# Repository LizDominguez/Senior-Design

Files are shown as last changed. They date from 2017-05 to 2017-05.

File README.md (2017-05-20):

# Senior-Design
An IoT project including an RFID reader that updates a website listing adoptable pets. 

MYshelter is an animal shelter management system that keeps track of the pets that are surrendered and adopted. 
Each animal is given an RF tag with a unique ID. 
The ID is scanned once when the animal is surrendered to the shelter, and a second time once the animal is adopted. 
This information will be sent to a database that keeps track of the animals and other relevant information.

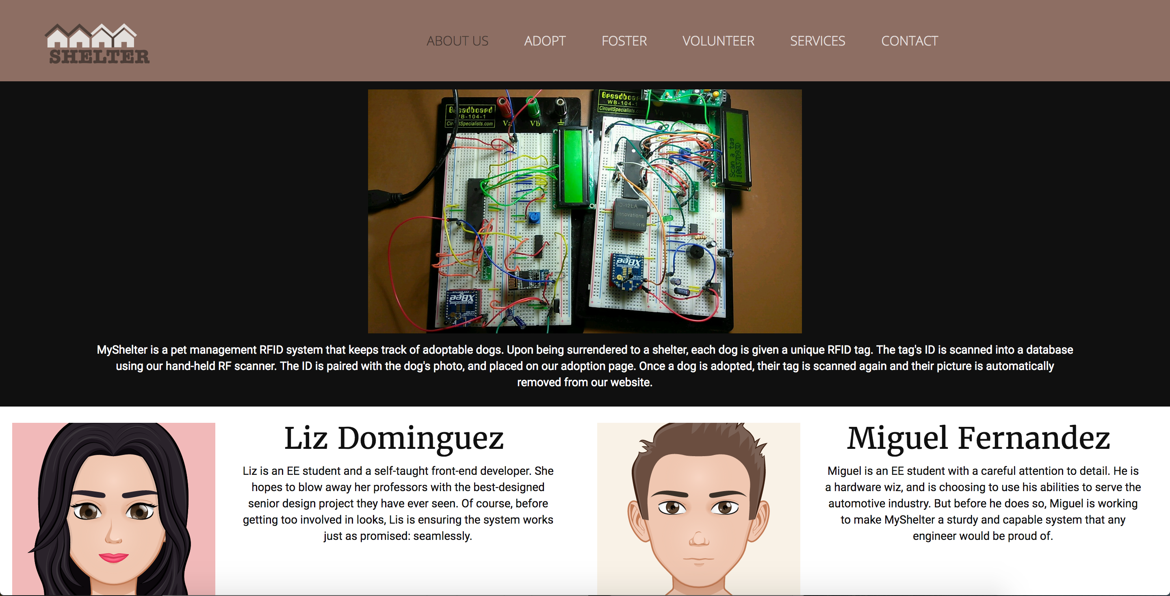
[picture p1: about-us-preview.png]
 
The MyShelter Website

Project Features:

This design requires RFID tags, a receiver circuit, and a Wi-Fi module. 
The receiver will use a 125kHz carrier signal to power the RFID tag via an antenna. 
An AM signal demodulator will retrieve the stored information on the RFID tag in digital form. 
Amplifiers will be used in the receiver circuit to amplify the analog signals for better data interpretation. 
The microprocessor will then retrieve the signal information and decode it. The microprocessors uses UARTs, LCDs, XBEEs, the PWM, timers,
interrupts, ISP, a wifi module, and other features.

<div align="center">

Watch the video (https://youtu.be/Qfhe00SMSjw)

Click to watch the project in action
</div>

For more information, view the <a href="https://github.com/LizDominguez/Senior-Design/blob/master/Final%20Report.pdf">design report</a>.

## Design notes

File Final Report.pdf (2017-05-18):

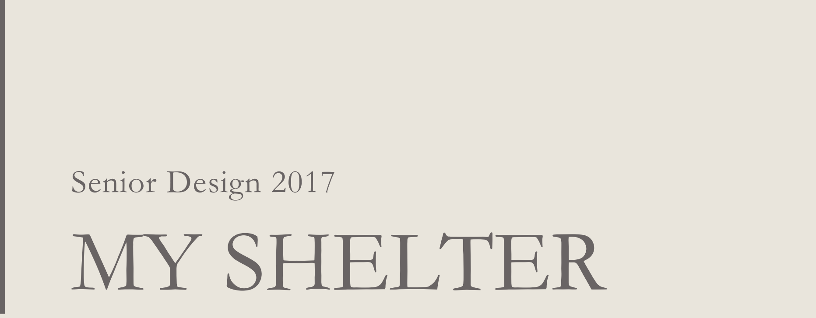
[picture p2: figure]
Senior Design 2017 MY SHELTER
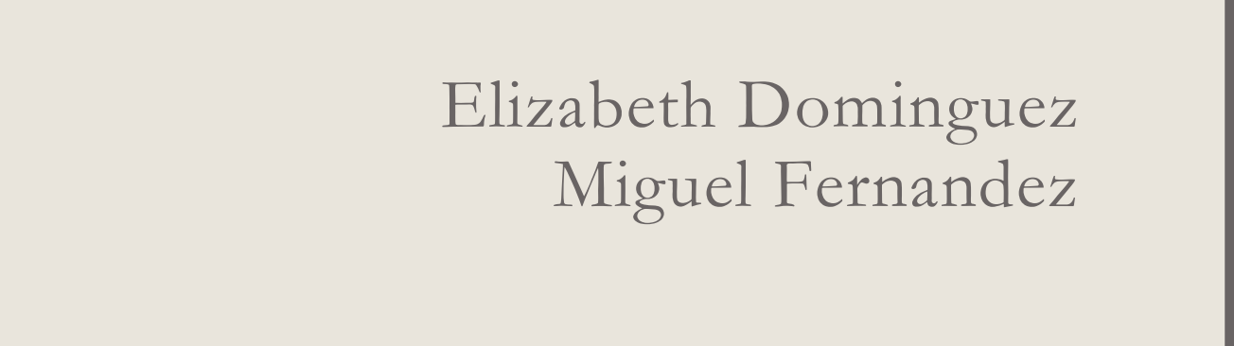
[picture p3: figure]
Elizabeth Dominguez Miguel Fernandez

## Project Abstract

MYshelter is an animal shelter management system that keeps track of the pets that are surrendered and adopted. Each animal is given an RF tag with a unique ID, like the one shown in Figure 1. The ID is scanned once when the animal is surrendered to the shelter, and a second time once the animal is adopted. This information will be sent to a database that keeps track of the animals and other relevant information. An example of what may appear on the database is shown in Table 1.

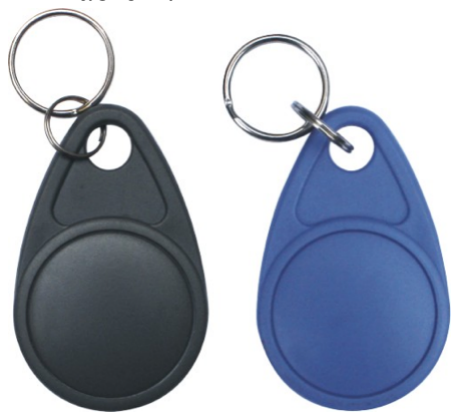
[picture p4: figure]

FIGURE 1 RF TAG GIVEN TO EACH PET

TABLE 1 INFORMATION STORED IN DATABASE

ID | TYPE | BREED | STATUS
12345 | DOG | HUSKY | SURRENDERED
23456 | CAT | TABBY | ADOPTED

The information on this database will then be used on an adoption website Figure 2. The website will showcase pictures of the available pets. If an animal is adopted, its picture will be blurred out on the website once the page is refreshed. The website also has an administration page that allows users to change the IDs of each dog without having to scan the tag.

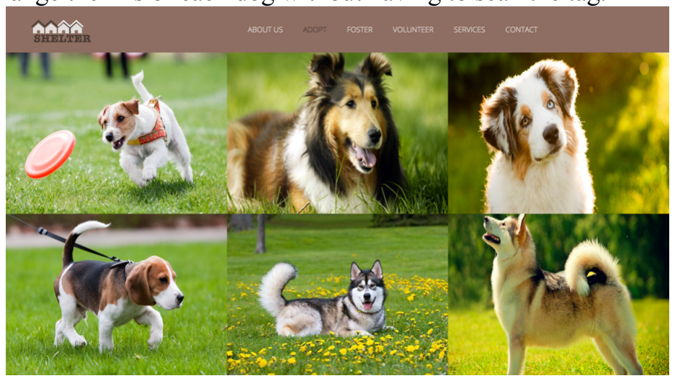
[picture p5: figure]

FIGURE 2 THE MYSHELTER WEBSITE

Project Features
This design requires RFID tags, a receiver circuit, and a Wi-Fi module. The receiver will use a 125kHz carrier signal to power the RFID tag via an antenna. An AM signal demodulator will retrieve the stored information on the RFID tag in digital form. The receiver must obtain information accurately with minimal interference. Amplifiers will be used in the receiver circuit to amplify the analog signals for better data interpretation. The microprocessor will then retrieve the signal information and decode it.

Our design will be split into two systems: the mainboard with the Wi-Fi module, and a handheld RF module. Both systems use an LCD and XBEEs to communicated via UART. The receiver module is also hooked up to an AB amplifier and an 8 ohm speaker that beeps whenever a card is successfully read. Our system is powered by two 6V wall plugs and on/off switches.
Concept & Technology Selection
Our design will include the following components:
- 2 Atmega644PA
- RF Antenna
- RFID cards
- Receiver
- 2 LCDs
- 2 XBEEs
- Wi-Fi module
- AB amplifier and 8 ohm speaker
- Power Connectors

## RF Reader

Our RF reader reads 125 kHz tags and uses the EM4100 protocol to produce level transitions in the middle of a bit period. A low to high transition signifies a logic of 1, and a high to low transition signifies a 0. When the tag approaches the electromagnetic field of the antenna, it sends out a stream of bits shown in Figure 3. The first 9 bits are 1s, used to indicate the beginning of a read. They are followed by 8 customer ID numbers, each with their own parity bits. Then 32 data bits and their parities are sent as the card ID. Finally, 4 column parity bits and 1 stop bit are transmitted for a total of 64 bits.

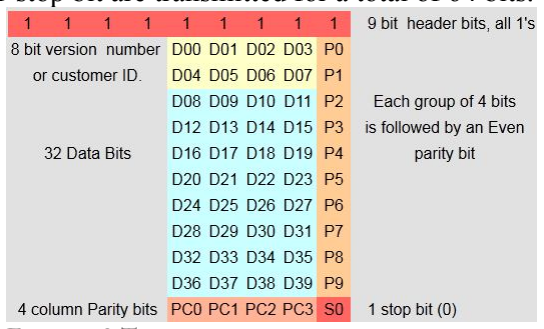
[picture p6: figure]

FIGURE 3 THE TRANSMITTED BIT STREAM

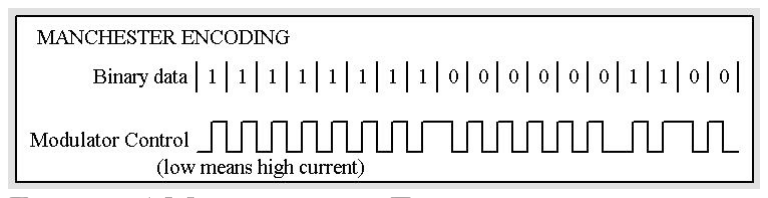
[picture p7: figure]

FIGURE 4 MANCHESTER ENCODING

In order to combat the noise in our receiver circuit, we attached bypass capacitors to power lines in addition to a Schmitt trigger. A Schmitt trigger is a comparator with hysteresis that converts analog to digital. Its output changes only when the input changes past a second threshold.
A 125kHz square wave is generated via counter 2 on PIND7 and fed into the input of the receiver. The output of the receiver is then connected to an input pin of the microcontroller. Using a 16-bit, timer, we store the logic value ever 500 us into a large buffer. Then a counter counts each set of 9 1s—whenever the input pin reads 0, it resets the count to 0 to only account for consecutive 1s. Another array then stores where each consecutive 9 1s are in the buffer and increments this value to begin at the first value of the 50 card ID values and parity bits.
Once the buffer is full, the data is decoded. Each bit is shifted 4 times to create a 4-bit integer. The parity and column parity bits are saved. We then calculate what the column and row parity bits should be in a separate loop. If the scanned and calculated parity bits do not match, we do not print the value. Only when we have a perfect read to we print he values we scanned.

## AB Amplifier

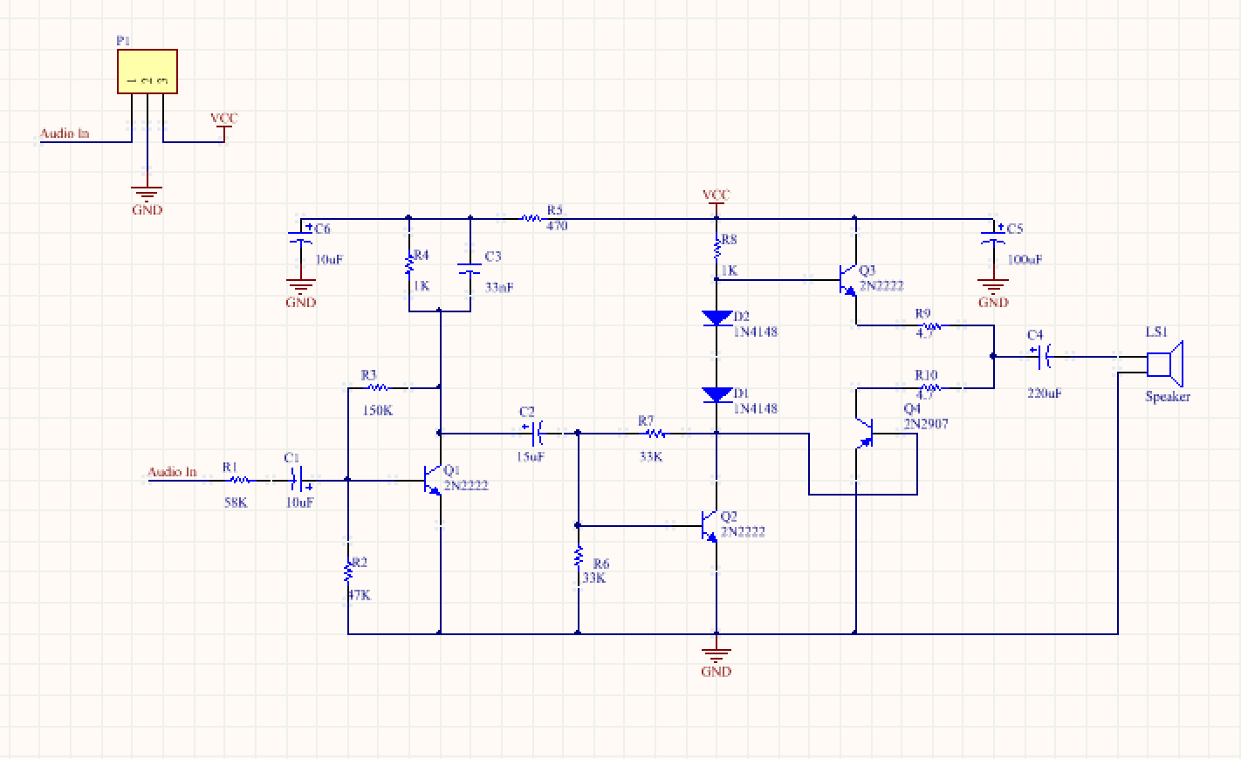
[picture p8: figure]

FIGURE 5 AB AMPLIFIER CIRCUIT

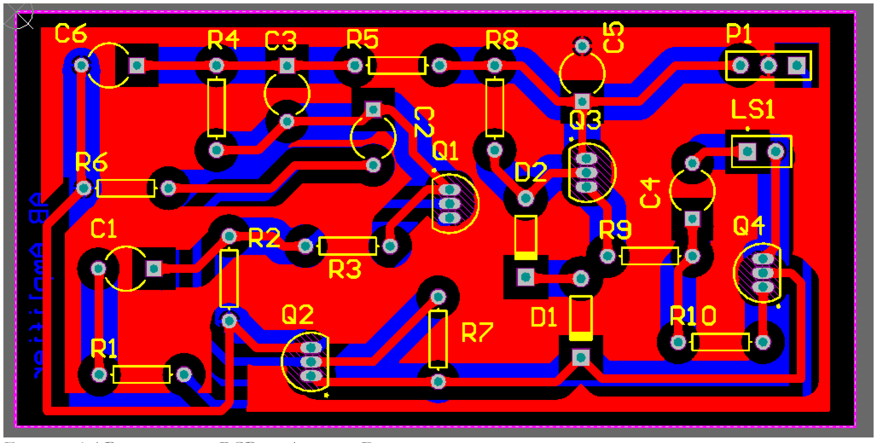
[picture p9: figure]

FIGURE 6 AB AMPLIFIER PCB IN ALTIUM DESIGNER
Preamplifier Stage
Transistor Q1 and the surrounding components act as a preamplifier. A preamplifier is a component that provides a small gain to a signal before it is fed to an amplifier with a greater gain. This is done because many audio sources have a small output voltage that would not be enough to drive a speaker. The preamplifier stage also acts as a volume control and noise filter. Transistor Q1 is dual feedback biased using R2, R3, and R4. Biasing sets the transistor DC operating voltage and current to the levels that prevents the AC signal from clipping. It is done because transistors cannot conduct if the voltage/current is negative, which it is in an audio signal. Therefore, the input signal must be shifted into the positive region.
This can be done with collector feedback biasing, also called self-biasing, using R3 and R4. Referring to figure 3, self-biasing works in the following way: If Ic increases, Vc decreases, reducing the base drive and automatically reducing collector current (keeping the Q point fixed). Negative feedback is supplied via Rb1 so that when the load current increases, Vc decreases, causing Ib to decrease, and bringing Ic back to normal. Adding R2 to the circuit makes it dual feedback biased, providing additional stability through automatic biasing and Rf feedback.

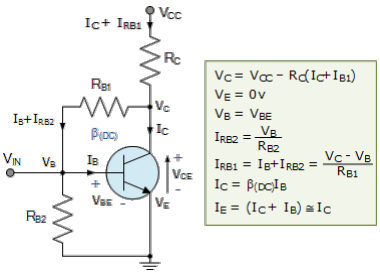
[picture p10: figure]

FIGURE 7 DUAL FEEDBACK BIASING

Driver Stage
Q2 acts as the driver stage. The driver stage’s purpose is to produce enough current gain to drive the output stage. This in turn causes a gain in power.
AB push pull
Transistors Q3 and Q4 and diodes D1 and D2 form part of the push-pull stage with diode biasing. Temperature can vary the base-emitter voltage. This can be prevented by forward biasing via two diodes. The alternating transistors source or sink the load current, which improves efficiency, increases the power output, cancels even harmonics, and cancels DC current at the output.

## Wi-Fi Module

For our Wi-Fi module, we chose the ESP8266, shown below. This module is used most often by hobbyists and beginners due to its short and simple AT commands. It is also one of the cheapest modules on the market, at only $3.00. Just a few years ago, Wi-Fi modules were priced at over $50!

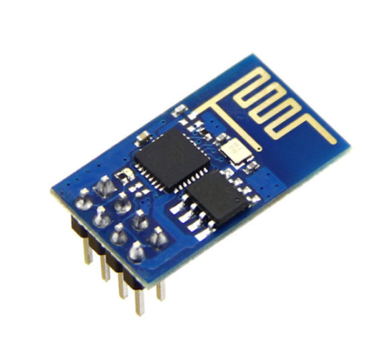
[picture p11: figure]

FIGURE 8 THE ESP8266 MODULE

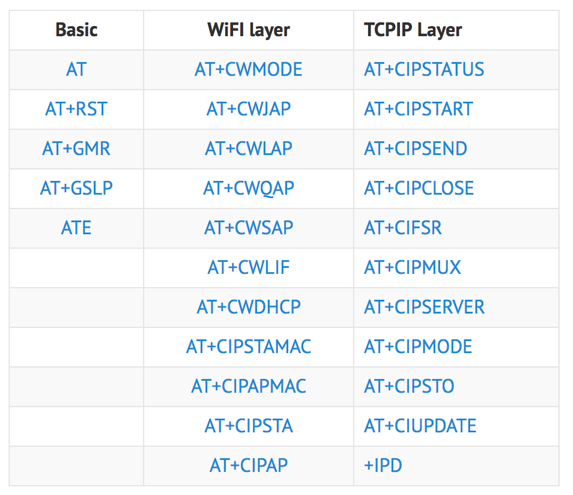
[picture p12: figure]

FIGURE 1 ALL KNOWN AT COMMANDS

We utilized a mobile hotspot to share access to our phone’s wireless network connection with the Wi-Fi module. Wi-Fi utilizes radio waves at a frequency of 2.4 or 5 GHz to establish a connection to a network. Once data is translated into a radio signal, an antenna will transmit to a router. The data is then decoded and sent through the internet via an Ethernet cable. The speed and frequency of transmission are highlighted by the 802.11 network standards a, b, g, and n. Once a connection is established, we send an HTTP request to our server hosted on Amazon Web Services (AWS). HTTP is short for hypertext transfer protocol. When an HTTP request is submitted to a server, the server returns a response message.
A server is a resource provider. It holds HTML files and other content. It can be accessed via a web browser, remote client, or ssh remote login. The server itself is made up of a local client, or a program on the same machine as the server, like MySQL. To pass SQL queries to the server, a programmer must use a scripting language. Initially we considered using JavaScript as our primary scripting language, used solely for web browsers. However, we opted for a simpler general-purpose language called Python.
Connecting to a server also requires an IP address. An Internet Protocol address consists of four numbers ranging from 0 to 255 that designate the destination of the information we send. We also include a port number at which the virtual machine listens in for data.
The Wi-Fi module communicates with the Atmega644PA via UART at 9600 baud. UART0 listens in for the RF ID being sent from the XBEE. The ID is compared to a structure array holding all card values. When there’s a match, the microcontroller then decides the status of the dog and prints it on the LCD along with the card ID. Initially, a dog is surrendered and already on the website. Once the card is scanned again, and the dog’s status changes, the Wi-FI module sends a GET request—to the server with the card ID and the status in order to override the current status stored in an SQL table. Then python executes the script responsible for changing the dog’s picture on the front-end of the website. When a person visits the website, the browser will send a GET request to the server to generate the HTML files.

## Final Design Schematics and PCBs

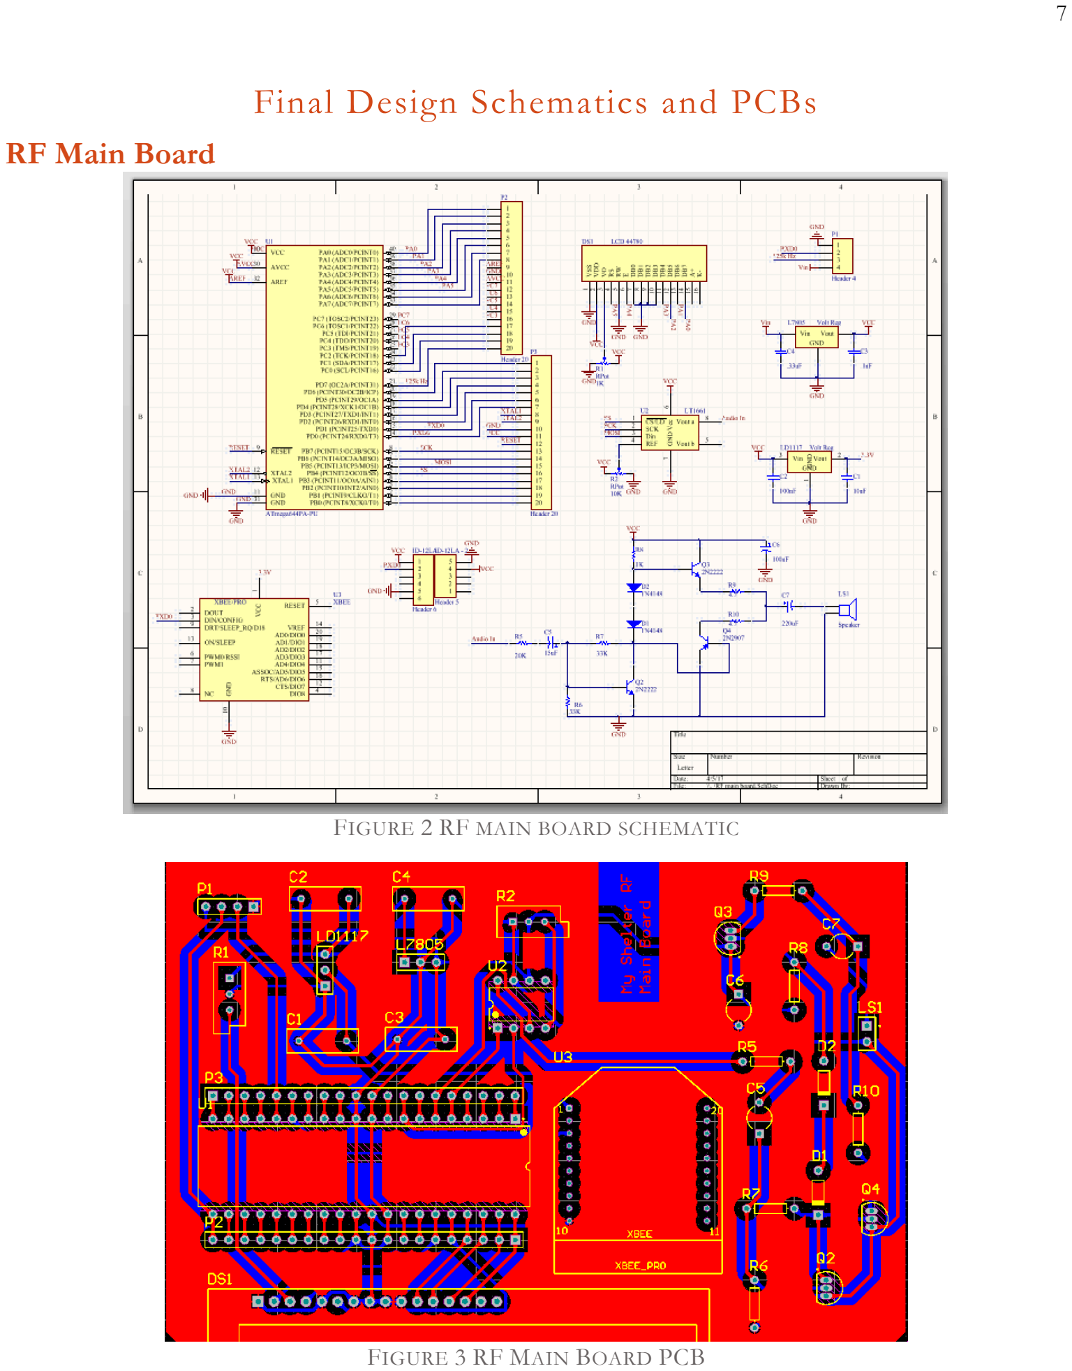
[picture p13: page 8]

RF Main Board

FIGURE 2 RF MAIN BOARD SCHEMATIC

FIGURE 3 RF MAIN BOARD PCB

Wi-FI Main Board

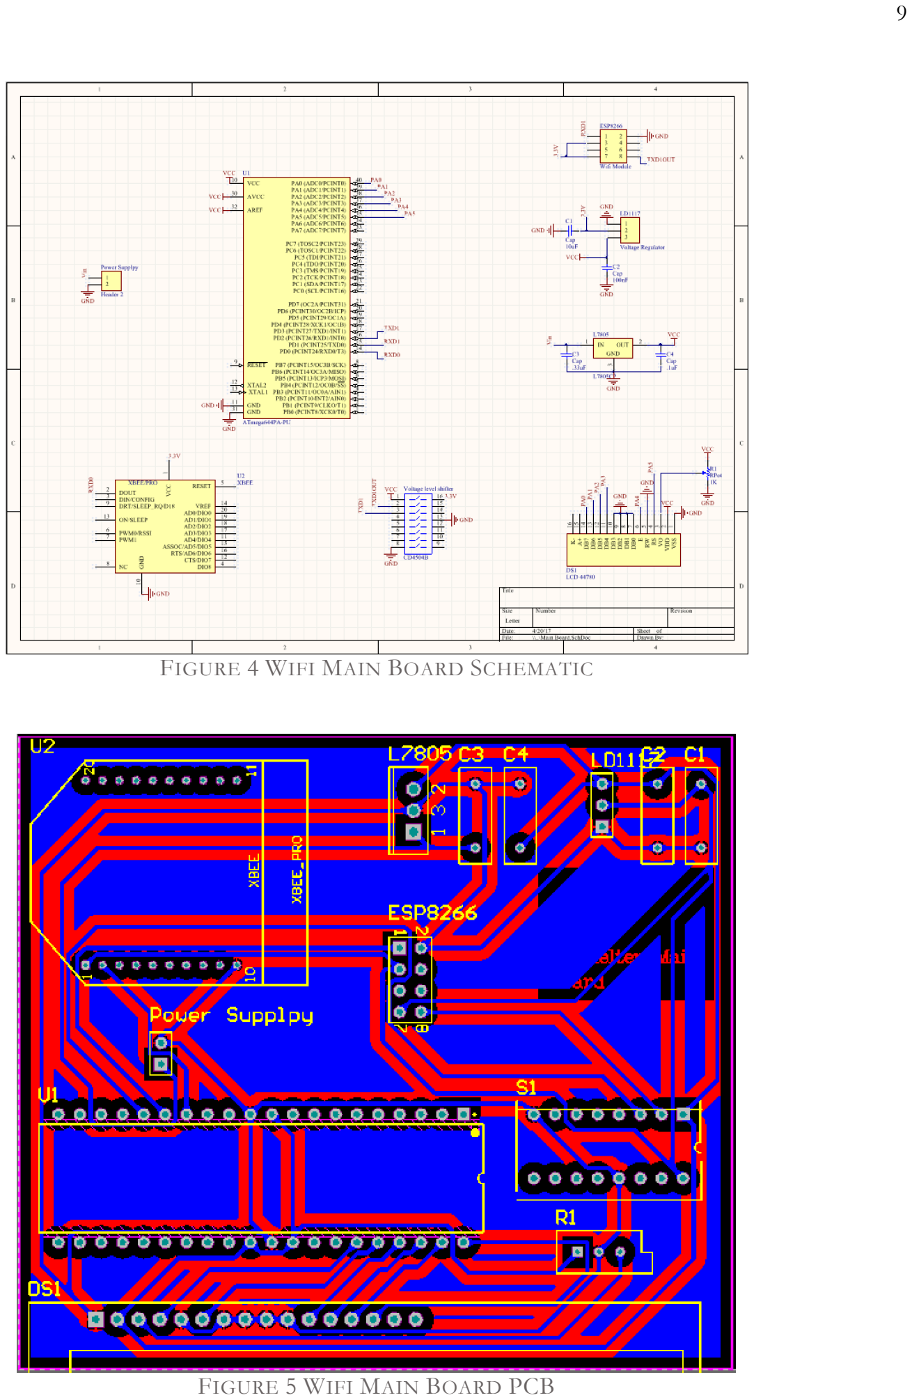
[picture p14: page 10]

FIGURE 4 WIFI MAIN BOARD SCHEMATIC

FIGURE 5 WIFI MAIN BOARD PCB

## Work Break-Down

Task | Liz | Miguel
RFID Receiver | 0% | 100%
Battery Charging Circuit | 0% | 100%
AB Amplifier | 100% | 0%
Main Board Programming | 100% | 0%
Main Board PCB | 0% | 100%
Database & Website | 100% | 0%
RF Programming | 90% | 10%
RF PCB | 70% | 30%
Case | 0% | 100%

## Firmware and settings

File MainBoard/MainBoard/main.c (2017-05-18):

#define F_CPU 8000000UL
#include <avr/io.h>
#include <inttypes.h>
#include <avr/interrupt.h>
#include <stdlib.h>
#include <stdio.h>
#include <stdbool.h>
#include <util/delay.h>
#include <string.h>

#define BAUD 9600
#define BAUDRATE (((F_CPU / (BAUD * 16UL))) - 1)
#define ICP PIND6
#define IP     "35.162.87.20" 


/********************************************************************** LCD Configuration ********************************************************************/

#define lcdDdr		DDRA		//Data direction
#define lcdPort		PORTA		//PortD
#define lcdD7Bit	PORTA0		//LCD D7 (pin 14) -> PORTD7
#define lcdD6Bit	PORTA1		//LCD D6 (pin 13) -> PORTD6
#define lcdD5Bit	PORTA2		//LCD D5 (pin 12) -> PORTD5
#define lcdD4Bit	PORTA3		//LCD D4 (pin 11) -> PORTD4
#define lcdEBit		PORTA4		//LCD E (pin 6)   -> PORTD3
#define lcdRSBit	PORTA5		//LCD RS (pin 4)  -> PORTD2

#define lineOne			0x00                // Line 1
#define lineTwo			0x40                // Line 2
#define clear           0b00000001          // clears all characters
#define home            0b00000010          // returns cursor to home
#define entryMode       0b00000110          // moves cursor from left to right
#define off      		0b00001000          // LCD off
#define on       		0b00001100          // LCD on
#define reset   		0b00110000          // reset the LCD
#define bit4Mode 		0b00101000          // we are using 4 bits of data
#define setCursor       0b10000000          //sets the position of cursor

void lcd_write(uint8_t);
void lcd_instruction(uint8_t);
void lcd_char(uint8_t);
void lcd_string(uint8_t string[]);
void lcd_init(void);


void lcd_init(void)
{
	lcdDdr |= (1 << lcdD7Bit) | (1 << lcdD6Bit) | (1 << lcdD5Bit) | (1 << lcdD4Bit) | (1 << lcdEBit) | (1 << lcdRSBit);
	_delay_ms(100);

	lcdPort &= ~(1 << lcdRSBit);                 // RS low
	lcdPort &= ~(1 << lcdEBit);                 // E low

	// LCD resets
	lcd_write(reset);
	_delay_ms(8);                           // 5 ms delay min

	lcd_write(reset);
	_delay_us(200);                       // 100 us delay min

	lcd_write(reset);
	_delay_us(200);
	
	lcd_write(bit4Mode);               	//set to 4 bit mode
	_delay_us(50);                     // 40us delay min

	lcd_instruction(bit4Mode);   	 // set 4 bit mode
	_delay_us(50);                  // 40 us delay min

	// display off
	lcd_instruction(off);        	// turn off display
	_delay_us(50);

	// Clear display
	lcd_instruction(clear);              // clear display
	_delay_ms(3);                       // 1.64 ms delay min

	// entry mode
	lcd_instruction(entryMode);          // this instruction shifts the cursor
	_delay_us(40);                      // 40 us delay min

	// Display on
	lcd_instruction(on);          // turn on the display
	_delay_us(50);               // same delay as off
}


void lcd_string(uint8_t string[])
{
	int i = 0;                             //while the string is not empty
	while (string[i] != 0)
	{
		lcd_char(string[i]);
		i++;
		_delay_us(50);                              //40 us delay min
	}
}


void lcd_char(uint8_t data)
{
	lcdPort |= (1 << lcdRSBit);                 // RS high
	lcdPort &= ~(1 << lcdEBit);                // E low
	lcd_write(data);                          // write the upper four bits of data
	lcd_write(data << 4);                    // write the lower 4 bits of data
}


void lcd_instruction(uint8_t instruction)
{
	lcdPort &= ~(1 << lcdRSBit);                // RS low
	lcdPort &= ~(1 << lcdEBit);                // E low
	lcd_write(instruction);                   // write the upper 4 bits of data
	 _delay_us(10);
	lcd_write(instruction << 4);             // write the lower 4 bits of data
	  _delay_ms(5);
}


void lcd_write(uint8_t byte)
{
	lcdPort &= ~(1 << lcdD7Bit);                        // assume that data is '0'
	if (byte & 1 << 7) lcdPort |= (1 << lcdD7Bit);     // make data = '1' if necessary

	lcdPort &= ~(1 << lcdD6Bit);                        // repeat for each data bit
	if (byte & 1 << 6) lcdPort |= (1 << lcdD6Bit);

	lcdPort &= ~(1 << lcdD5Bit);
	if (byte & 1 << 5) lcdPort |= (1 << lcdD5Bit);

	lcdPort &= ~(1 << lcdD4Bit);
	if (byte & 1 << 4) lcdPort |= (1 << lcdD4Bit);

	// write the data
	
	lcdPort |= (1 << lcdEBit);                   // E high
	_delay_us(1);                               // data setup
	lcdPort &= ~(1 << lcdEBit);                // E low
	_delay_us(1);                             // hold data
}

/******************************************************************* RFID Configuration ********************************************************************/

typedef enum {adopted, surrendered} dog_status;

struct {
	char tag[12 + 1];
	dog_status status;
}
cards[3] = {
	[0].tag = {0x00, 0x32, 0x43, 0x30, 0x30, 0x41, 0x43, 0x36, 0x39, 0x33, 0x45, 0x00, 0x00}, //2C00AC693E
	[0].status = surrendered,
	[1].tag = {0x00, 0x33, 0x31, 0x30, 0x30, 0x33, 0x37, 0x44, 0x39, 0x33, 0x44, 0x00, 0x00}, //310037D93D
	[1].status = surrendered,
	[2].tag = {0x00, 0x36, 0x46, 0x30, 0x30, 0x35, 0x43, 0x41, 0x44, 0x36, 0x30, 0x00, 0x00}, //6F005CAD60
	[2].status = surrendered
};

void USART_RF_init(void)
{
	/*Set baud rate */
	UBRR0H = (BAUDRATE>>8);
	UBRR0L = BAUDRATE;
	
	/* Enable receiver and transmitter */
	UCSR0B = (1<<RXEN0)|(1<<TXEN0);

	/* Set frame format: 8data, 1stop bit, no parity */
	UCSR0C = (3<<UCSZ00);
	
	/* Enable interrupt */
	UCSR0B |= (1 << RXCIE0);

}

unsigned char USART_RF_receive(void)
{
	/* Wait for data to be received */
	while(~(UCSR0A) & (1<<RXC0));

	/* Get and return received data from buffer */
	return UDR0;
}

void USART_RF_send(unsigned char data)
{
	/* Wait for data to be received */
	while (!( UCSR0A & (1<<UDRE0)));
	UDR0 = data;
}

struct {
	/* RFID buffer */
	volatile char ID[12 + 1];
	volatile uint8_t index;
	volatile bool done;
}RF;

inline void RFID_done(void) {
	while(!RF.done);
}

inline void RFID_ready(void) {
	/* RFID buffer is ready to be refilled*/
	RF.done = false;
}

char * get_card_id(int8_t index) {
	char * rfid = (index == -1)? (char *) RF.ID : cards[index].tag;
	return  (rfid + 1); 
}

int find_card(void) {
	for (int i = 0; i < 3; i++) {
		if (strcmp(cards[i].tag + 1, (char *)(RF.ID + 1)) == 0) {
			return i;
		}
	}
	return -1;
}

ISR(USART0_RX_vect) {
	char num = USART_RF_receive();
	
	if (!RF.done) {

	RF.ID[RF.index++] = num;
	if (RF.index >= 12) { 
		RF.index = 0;
		RF.ID[12 - 1] = RF.ID[0] = 0; 
		RF.done = true; 
	}
	}
}


/******************************************************************* Wifi Configuration *****************************************************************/

#define ROWS 15
#define COLS 52

struct {
	volatile char response[ROWS][COLS];
	volatile uint8_t row_index;
	volatile uint8_t col_index;
} Wifi;

void USART_Wifi_init(void) {
	
	UBRR1H = (BAUDRATE>>8);
	UBRR1L = BAUDRATE;
	UCSR1B = (1<<TXEN1) | (1<<RXEN1);
	UCSR1C = (3<<UCSZ10);
	UCSR1B |= (1 << RXCIE1);
	
	while(1){
		clear_response();
		USART_Wifi_cmd("AT+RST");
		
		lcd_instruction(clear);
		lcd_string((uint8_t *)"Configuring Wifi...");
		_delay_ms(1000);
		
		if (!Wifi_response("ready")) {
			lcd_instruction(clear);
			lcd_string((uint8_t *)"Hardware error"); //USART not connected
			lcd_instruction(setCursor | lineTwo);
			lcd_string((uint8_t *)"Restarting...");
			_delay_ms(1000);
			continue;
		}
		
		USART_Wifi_cmd("ATE0");
		_delay_ms(500);
		
		if (!connected()) continue;       // restarting if wifi is not responding
		upload_to_server("----------",'b');
		break;
	}
}


void USART_Wifi_send(unsigned char data) {
	while (!( UCSR1A & (1<<UDRE1)));
	UDR1 = data;
}

unsigned char USART_Wifi_receive(void) {
	while(~(UCSR1A) & (1<<RXC1));
	return UDR1;
}

void USART_Wifi_cmd(char string[]) {
	for (int i = 0; string[i] != 0; i++) {
		USART_Wifi_send(string[i]);
	}
	USART_Wifi_send(0x0D);
	USART_Wifi_send(0x0A);
}

bool Wifi_response(char string[]) {
	for (int i = 0; i < ROWS - 1; i++) {
		if(strcmp((char *)Wifi.response[i], string) == 0) {
			Wifi.response[i][0] = 0; 
			return true;
		}
	}
	return false;
}

void clear_response(void) {
	for (int i = 0; i < ROWS - 1; i++) {
		Wifi.response[i][0] = 0;
	}
	Wifi.row_index = 0;
	Wifi.col_index = 0;
}

bool connected(void) {
	
	lcd_instruction(clear);
	lcd_string((uint8_t *) "Wifi is...         ");
	
	while(1) {
		lcd_instruction(setCursor | lineTwo);
		USART_Wifi_cmd("AT+CIPSTATUS");
		_delay_ms(500);
		
		if (Wifi_response("STATUS:2")) {
			lcd_string((uint8_t *)"Connected!       ");
			clear_response();
			return true;
		} 
			
		else if (Wifi_response("STATUS:5")) {
			lcd_string((uint8_t *)"Not Connected.  ");
			clear_response();
		} 
			
		else {
			lcd_string((uint8_t *)"Not Responding.   ");
			return false;
		}

	}
}


void upload_to_server(char * rfid, char action) {
	
	char HTTP_request_buffer[] = "GET /add/##########/& HTTP/1.0";
	
	for (int i = 0 ; i < 10; i++) { 
		HTTP_request_buffer[9 + i] = rfid[i];
	}
	
	HTTP_request_buffer[20] = action; 
	USART_Wifi_cmd("AT+CIPSTART=\"TCP\",\""IP"\",80");
	_delay_ms(1000);
	USART_Wifi_cmd("AT+CIPSEND=34");
	_delay_ms(1000);
	USART_Wifi_cmd(HTTP_request_buffer);
	USART_Wifi_cmd("");
	_delay_ms(1000);
}


ISR(USART1_RX_vect) {
	char c = USART_Wifi_receive();
	int row = Wifi.row_index, col = Wifi.col_index;
	Wifi.response[row][col] = c;
	
	if ((col > 0 && Wifi.response[row][col - 1] == 0x0D && Wifi.response[row][col] == 0x0A) || (col == COLS - 1)) {
		Wifi.response[row][col - 1] = 0; 
		Wifi.row_index = (row == ROWS - 1)? 0: row + 1;
		Wifi.col_index = 0;  
		return;
	}
	Wifi.col_index++;
}


void Scan_for_tag(void) {
	
	lcd_instruction(clear);
	lcd_string((uint8_t *)"Ready to Scan");
	_delay_ms(2000);
	
	RFID_done();
	
	lcd_instruction(clear);
	
	int card_index = find_card();
	
	if (card_index < 0) { 
		lcd_string((uint8_t *)"This card is new"); 
		_delay_ms(2000);
		lcd_instruction(clear);
		RFID_ready();
		return;
	}
	

	lcd_string((uint8_t *)get_card_id(card_index));
	lcd_instruction(setCursor | lineTwo);
	
	lcd_string((uint8_t *)"Dog is");
	
	RFID_ready();
	
	dog_status current_status = cards[card_index].status;
	char status_to_upload = '?';
	switch(current_status) {
		
		case adopted:
		cards[card_index].status = surrendered;
		lcd_string((uint8_t *) " surrendered");
		status_to_upload = 's';
		break;
		
		case surrendered:
		cards[card_index].status = adopted;
		lcd_string((uint8_t *) " adopted");
		status_to_upload = 'a';
		break;
	}
	
	upload_to_server(get_card_id(card_index), status_to_upload);
	lcd_instruction(clear);
	RFID_ready();
}


int main( void )
{
	
	lcd_init();
	USART_RF_init();
	USART_Wifi_init();
	lcd_instruction(clear);
	
	sei();
	
	
	while(1)
	{	
		Scan_for_tag();
	}
	
	return 0;


}

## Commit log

2017-02-06 prints only the RF ID
2017-02-09 output 125kHz square wave with PWM
2017-02-18 main board LCD
2017-02-21 changed PWM to timer 2 and added main board
2017-02-28 changed main board to 644PA
2017-03-26 fixing issues with uploading to server
    [main.c]
2017-03-27 fixed 2nd RF ID in buffer
    [main.c]
2017-04-04 SPI to DAC
2017-04-07 antenna fully functioning
2017-04-10 reads IDs correctly only on first attempt
    [main.c]
2017-04-14 added module to compare with antenna
2017-04-16 filters noisy reads
2017-04-16 reads continuously with no errors
    [main.c]
2017-04-19 reads correct values every time
    [main.c]
2017-05-18 Added all project files
    [AB_Amplifier.PcbDoc, AB_Amplifier.PrjPcb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]
